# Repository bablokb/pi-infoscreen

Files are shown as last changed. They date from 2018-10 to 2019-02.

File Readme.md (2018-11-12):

Pi-Infoscreen
=============

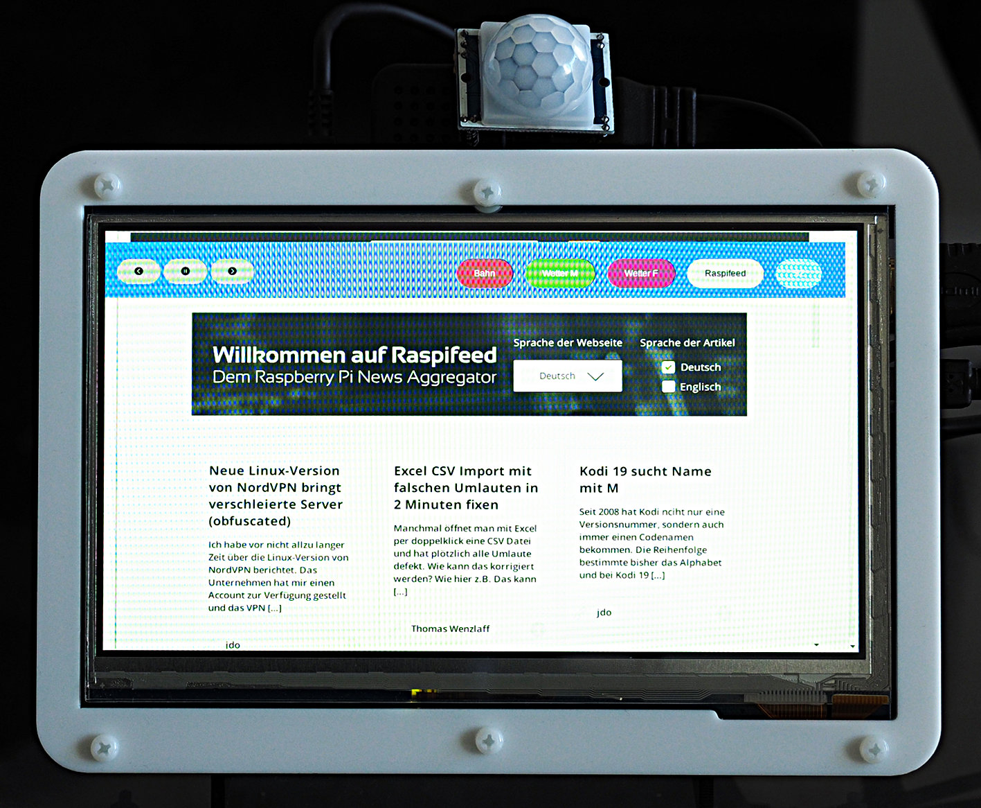
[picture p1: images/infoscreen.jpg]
The infoscreen in action


Overview
--------

This project implements a small infoscreen using a Pi and a 7"-touchscreen.
For efficiency reasons, the screen should only run while somebody is at
home, so the system automatically boots when it detects motion and automatically
shutsdown when nothing moves anymore.

Once booted, the system cycles through a list of predefined webpages.

Hardware
--------

The hardware consists of

  - a microcontroller (PIC12F675, but almost any microcontroller will do)
  - an IR motion sensor (HC-SR501, cheap and widely available)
  - a Pi3
  - a Waveshare 7"-touchscreen
  - a circuit with a P-channel mosfet

For details about the PIC and the circuit, browse the
[hardware-directory](hardware/ "hardware-directory").

Note that it is possible to run the infoscreen without the added luxury
of a PIC and/or an IR motion sensor. In case you don't have a PIC you
have to manually start the system (or let it run all the time). Since
using the sensor does not require soldering, you could use the sensor
together with the Pi to at least automatically shutdown your system.

States and Events
-----------------

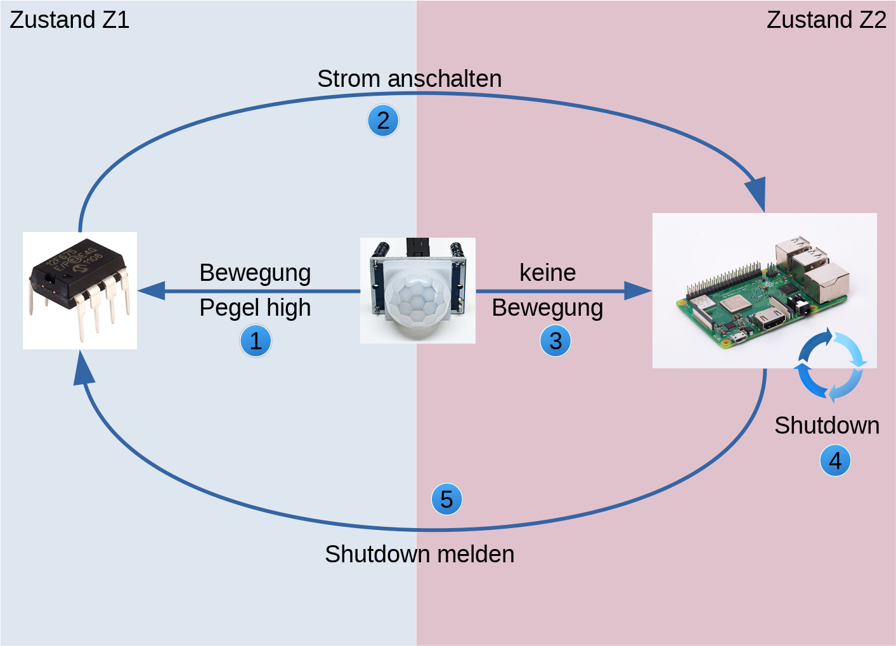
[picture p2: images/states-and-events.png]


The system starts in state "Z1": the Pi is shutdown and the PIC controls
the motion sensor (PIR). Motion will trigger a high-level on the out-pin
of the PIR, which is attached to the PIC. Now the PIC will set the gate of
the mosfet to low, thus turning on current for the Pi.

Now we are in state "Z2": the Pi is up and running and in charge of any
interrupts from the PIR. In this state the PIC is sleeping. Everytime the
Pi detects motion he will postpone his shutdown for a given time (e.g.
15 minutes). If there is no motion for 15 minutes, the Pi will shutdown
and pull Pin4 high. This is the signal for the PIC that we are back to
state "Z1" and to take over again.

Hardware Setup
--------------

The [circuit](hardware/pir_ctrl-circuit.gif "circuit") shows the wiring of
the project. The PIR-out is connected to the GP2 of the PIC as well as
GPIO17 of the Pi. In addition, GPIO4 of the Pi is connected to GP4 of the
PIC - the Pi uses this connection to signal shutdown to the PIC.

Note that this version

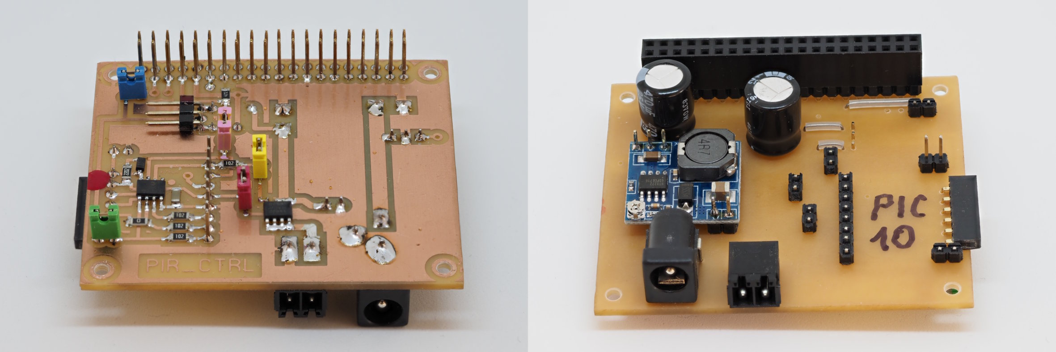
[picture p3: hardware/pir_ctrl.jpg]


also uses a step-down converter from 12V to 5V to supply a stable voltage
to the system.

Installation and Configuration
------------------------------

You should start out with a fresh install of Raspbian-Pixel desktop (tested
with Stretch, other versions might or might not work). Then run

    git clone https://github.com/bablokb/pi-infoscreen.git
    cd pi-infoscreen
    sudo tools/install
    cd ..
    git clone https://github.com/bablokb/gpio-poll-service.git
    cd gpio-poll-service
    sudo tools/install

The second install command will ask you to edit `/etc/gpio-poll.conf`, but
this is not necessary since the first install provides a suitable configuration.

*Note that the installation of the pi-infoscren project will alter your
`/boot/config.txt`. It configures HDMI for the 7"-touchscreen from Waveshare.
If you don't us this display then you must edit the file before rebooting
your system!*

The installation also modifies the autostart-behavior of the system. During
boot, it will automatically load chromium in kiosk-mode and show a local
web-page in app-mode which in turns cycles through a list of configured web-pages.

You can modify the autostart-behavior in
`/home/pi/.config/lxsession/LXDE-pi/autostart` and the list of web-pages in
`/usr/local/lib/iscreen/web/js/config.js`.

To make better use of the screen-space it is advisable to install a
so called "user-agent-switcher" within chromium from the chrome-webstore. Using
the switcher chromium can prentend to be running on a small device
(e.g. an iPhone6) and some (but not all) webpages will deliver pages
more suitable for small screens.

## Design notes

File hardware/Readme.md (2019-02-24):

Contents
========

This directory contains a number of gifs and jpegs with the circuit
and the layout of the hardware (including a gerber-file). It also
contains the assembler code used for the PIC12F675.

Assembling and Flashing
=======================

We use `gpasm` as the assembler and `pk2cmd` as flashing tools for the
PIC12F675. Both are available for the Raspberry Pi. For the latter you
also need the flashing tool /PICkit2/, which you can buy for a few
bucks on eBay.

Assembling
----------

In `pircontrol4.asm` you have to change the value of `OSCCAL`
(specific to the chip you use). Afterwards run, the assembler

    $ gpasm -a inhx8m pircontrol4.asm
    pircontrol4.asm:45:Warning [231] found lower case match for include filename

This will (re) create the file `pircontrol4.hex`.

Flashing
--------

Attach your PIC12F675 to your PICkit2 and run

    $ sudo pk2cmd -P PIC12F675 -X -M -F pircontrol4.hex
    PICkit 2 Program Report
    19-10-2018, 17:19:23
    Device Type: PIC12F675

    Program Succeeded.

    Operation Succeeded

That should be it.

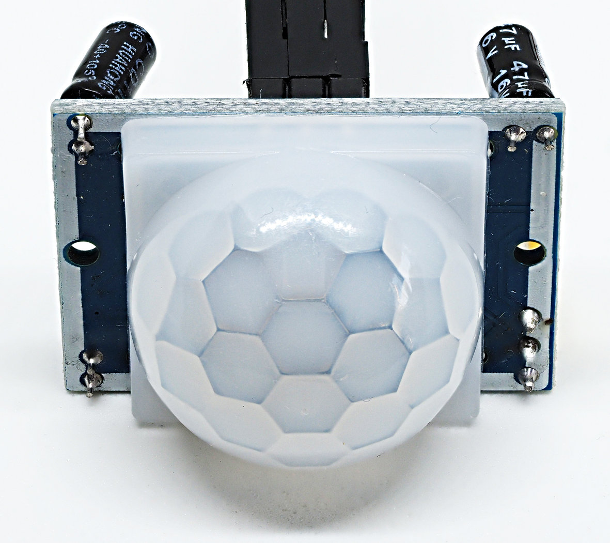
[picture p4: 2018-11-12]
hardware/HC-SR501.jpg

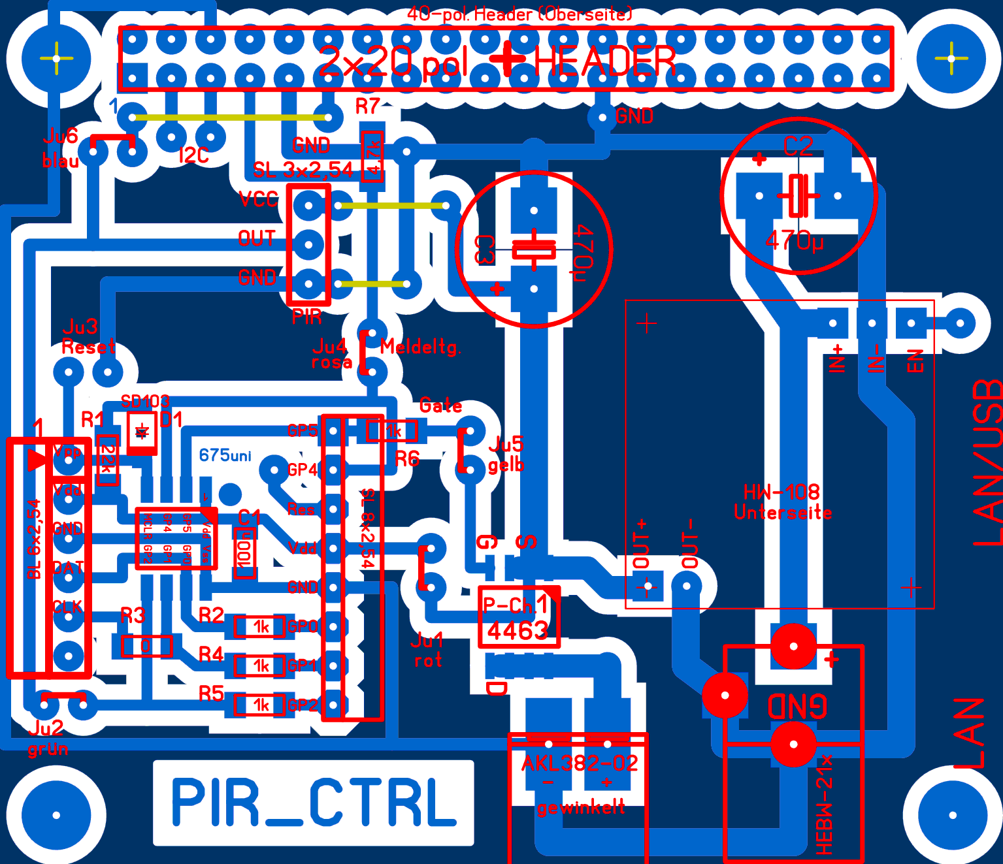
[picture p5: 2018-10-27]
hardware/pir_ctrl-layout.gif

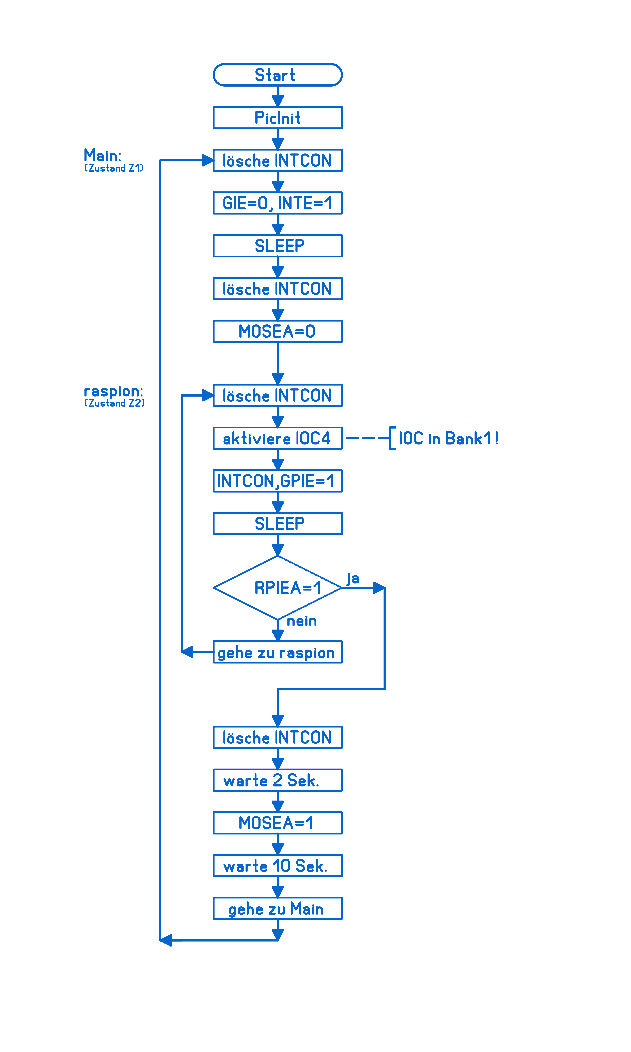
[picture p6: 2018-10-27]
hardware/pircontrol4-program-logic.gif

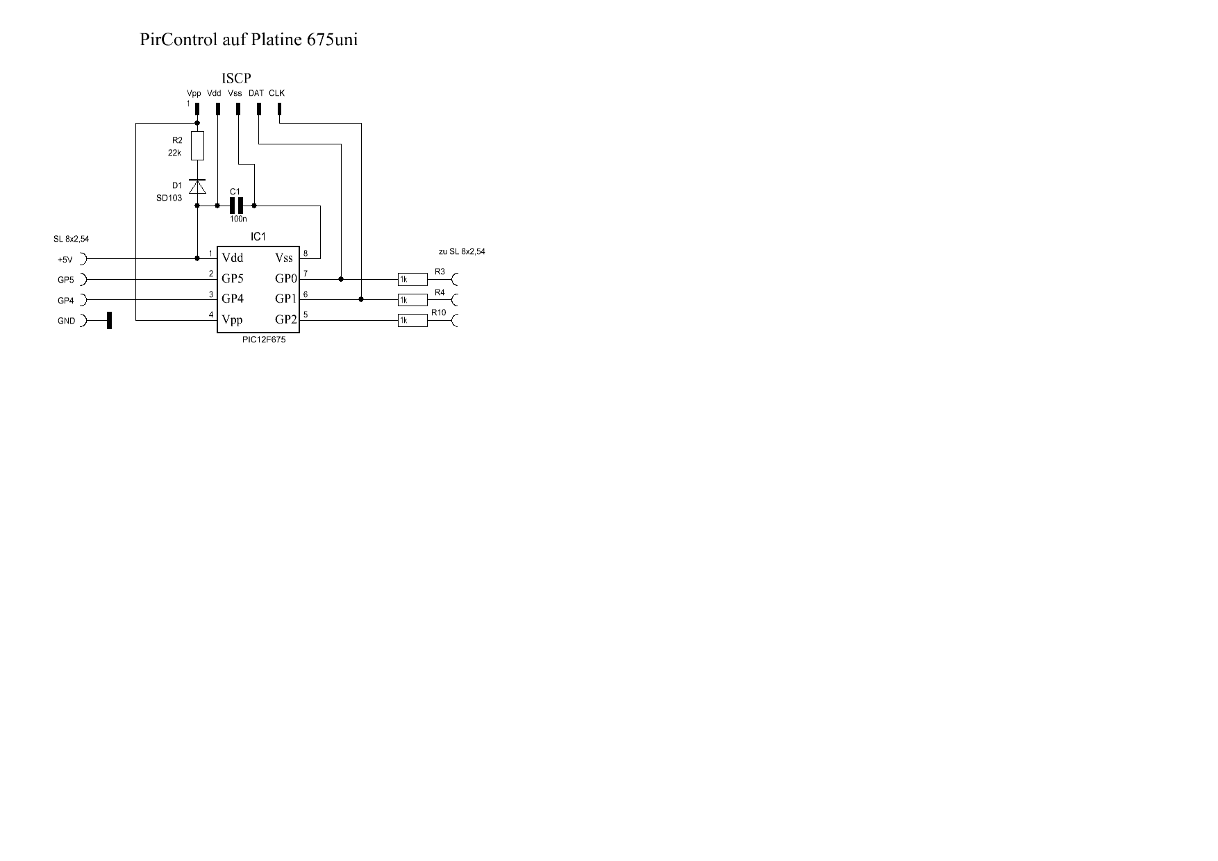
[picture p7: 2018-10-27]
hardware/675-circuit.gif

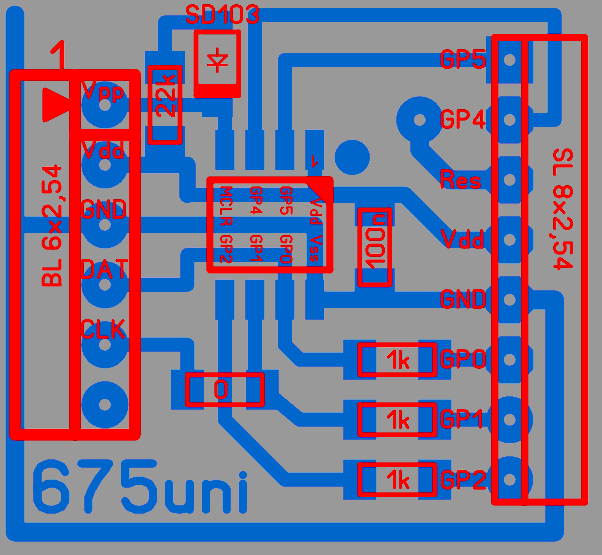
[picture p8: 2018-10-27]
hardware/675uni-layout.gif

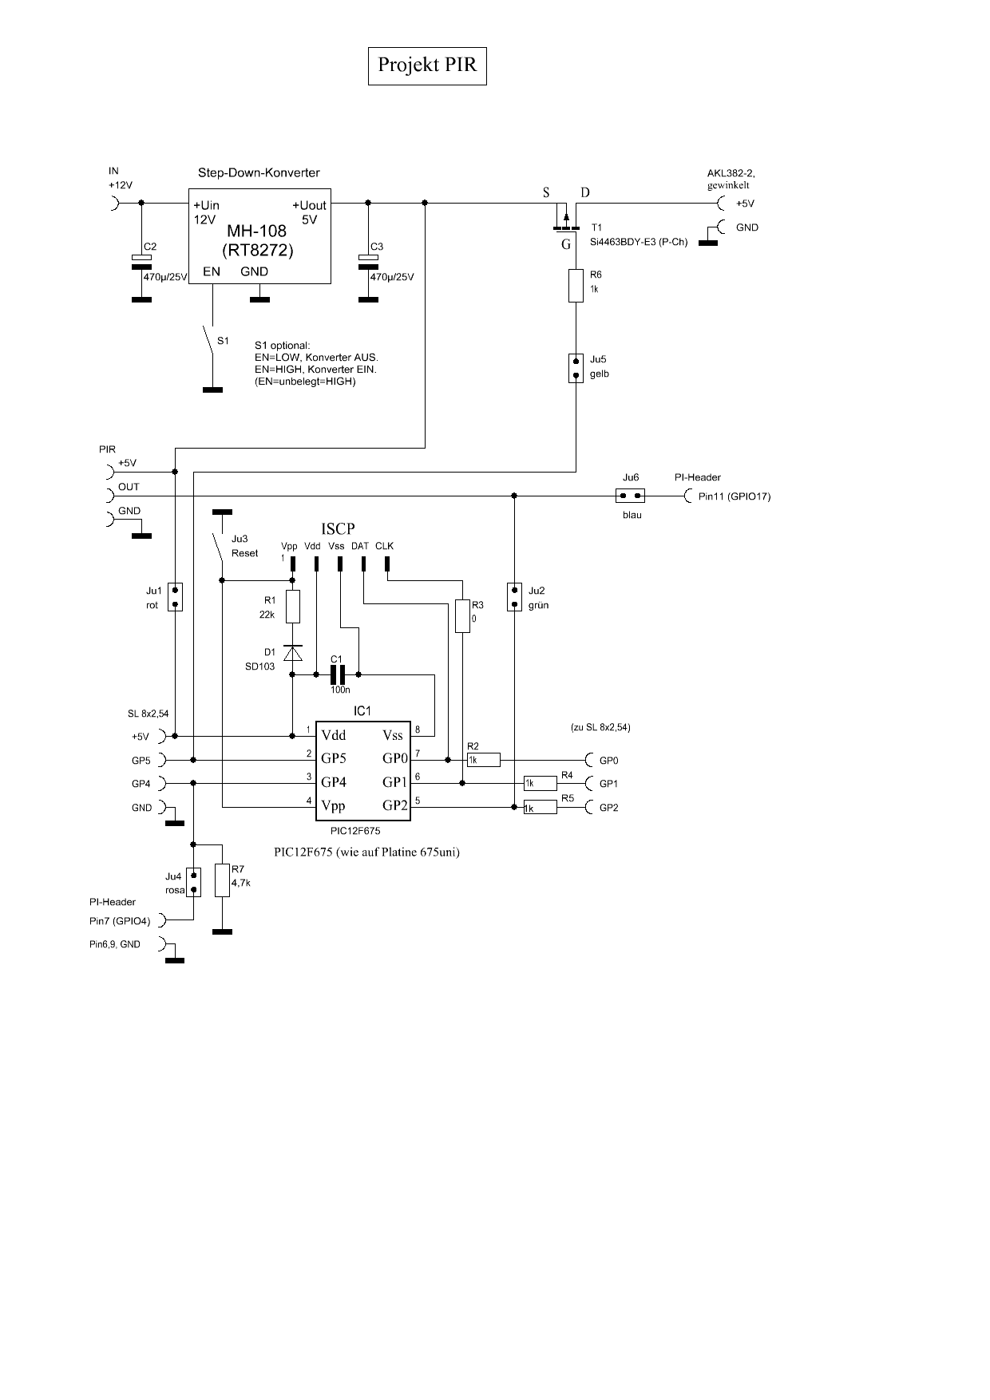
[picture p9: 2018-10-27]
hardware/pir_ctrl-circuit.gif

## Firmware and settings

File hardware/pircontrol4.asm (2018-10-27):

; pircontrol4.asm			Steinau, 12.10.2018
; ###########################################################
; IR-Bewegungsmelder-Ueberwachung mit PIC im Sleepmodus und
; einschalten eines Raspi (+5V) ueber GP5 per P-Ch-Mosfet.
; 1. Ausbau-Stufe: Test Sleep, mit LED an GP5 / Ergebnis:
; Wenn man mit High an GP2 tippt, leuchtet LED ca. 2 Sek.
; Ergebnis: 				       ok. 07.08.18
; 2. Ausbaustufe: Test PIR mit Pin OUT an GP2 / Ergebnis:
; Der PIR hat eine minimale EIN-Zeit von ca. 4-5 Sek., bevor
; diese nicht abgelaufen ist, läßt sich eine weitere Detektion
; nicht erreichen. Ergebnis:                   ok. 30.08.18
; 3. Ausbaustufe: Test der Interupts anhand der LED, rot
; Ergebnis: ok
; 4.Ausbaustufe: Endzustand komplett, mit Mosfet Si4463BDY
; Ergebnis:
; 
; ###########################################################
; Pinbelegung:
;
; GPI0	0 - GP0 Ausgang, nur ICSPDAT
;	1 - GP1 Ausgang, nur ICSPCLK
;	2 - GP2 Eingang, INT, steigende Flanke von PIR-OUT
;	3 - Vpp/MCLR
;	4 - GP4 Eingang, Meldeltg. v. Pi (Header Pin11/GPIO17)
;	5 - GP5 Ausgang, Gate T1 Mosfet Si4463
;
;	(Mosfet=Aus bei Gate=High)
;
; Prozessor-Takt 4 MHz, intern
; verwendete Platine: (Kalibrierwert OSCCAL!)
;
; Autor: Dipl.-Ing. Lothar Hiller
; ###########################################################
; Prozessor PIC12F675 (Fabrikzustand, Configuration: 01FF):
; PIC5:  OSCCAL: 3454, Bandgap: 1000, SMD, PIR, Bernh.
; PIC6:  OSCCAL: 3438, BandGap: 0000, SMD, PIR, Loth.
; PIC7:  OSCCAL: 3448, BandGap: 1000, DIL
; PIC8:  OSCCAL: 3430, BandGap: 1000, DIL, rosa
; PIC9:  OSCCAL: 3438, BandGap: 1000, DIL, lila
; PIC10: OSCCAL: 3450, BandGap: 0000, SMD, PIR_CTRL Bernh.
; ###########################################################
; Includedatei 12F675 einbinden:
	list       p=12f675
	#include   <P12f675.INC>
	ERRORLEVEL -302    ; SUPPRESS BANK SELECTION MESSAGES

; Configuration festlegen:
; MCLR ein, Power on Timer, kein WDT, int-Oscillator, 
; kein Brown out
	__CONFIG	_MCLRE_ON & _PWRTE_ON & _WDT_OFF & _INTRC_OSC_NOCLKOUT & _BODEN_OFF








; S2, Z59 ###################################################
; Variablen festlegen  (20h ... 5Fh):
; fuer Zeitverzoegerungen (UP'e in quarz_4MHz.asm)
miniteil	equ	0x20
miditeil	equ	0x21
maxiteil	equ	0x22
time0		equ	0x23
time1		equ	0x24
time2		equ	0x25
;
;
; ###########################################################
	org	0x00
	goto	PicInit		; PIC initialisieren
;
	org	0x04
				; fuer ISR, hier unbenutzt
;
	org	0x06
				; Initialisierung
PicInit
	; IO-Pins
	bcf	STATUS,RP0	; Bank0
	clrf	GPIO		; Init GPIOs
	movlw	0x07
	movwf	CMCON		; Comparator aus
	;
	; Ein/Ausgaenge und analog/digital festlegen (Bank1)
	bsf	STATUS,RP0	; Bank1
	clrf	ANSEL		; alles digital
	movlw	b'00010100'	; Eing.=1 oder Ausg.=0 festlegen:
	movwf	TRISIO		; Ausgang: GP0,1,5 Eingang: GP2,4
	;
	; OPTION_REG einstellen (Bank1)
	movlw	0xff
	movwf	OPTION_REG	; alle Bits auf high:
				; INTEDG=1 Int. bei steig. 
				; Flanke an GP2
				; PSA=1, fuer WDT unbenutzt
	;
	; internen Taktgenerator kalibrieren (Bank1)
	call	0x3FF
	movwf	OSCCAL		; 4-MHz-Kalibrierung
	bcf	STATUS,RP0	; Bank0
	;
	; Definitionen von Portpins:
;#define	PIROUT	GPIO,GP2	; pir-out an Eingang GP2
#define	RPIEA	GPIO,GP4	; Meldeleitung vom Raspi
#define	MOSEA	GPIO,GP5	; GP5 steuert gate p-Ch-Mosfet:
				; LOW=EIN, HIGH=AUS
	; GP5=1 ausgeben, damit T1 AUS ist !
	bsf	GPIO,GP5	; GP5=1, T1 AUS

	; PIR-Initialisierung abwarten:
	movlw	D'240'		; w = 240 (Dez)
	call	maxitime	; 240x250ms = 1 Min. warten
	movlw	D'240'
	call	maxitime	; noch eine Minute warten
;
; S3, Z118 ##################################################
Main
	; Zustand Z1 (PIC, GP2 ueberwacht PIR auf steig. Flanke)
	; Interruptbehandlung fuer Sleep:
	clrf	INTCON		; alle Int+Flags geloescht
	bsf	INTCON,INTE	; GP2/INT erlaubt, GIE=0 !
	SLEEP			; Sleep-Zustand aktivieren
	NOP
	clrf	INTCON		; alle INT sperren, INT-Flag=0
	;
	; PIR hat Bewegung detektiert, steigende Flanke an GP2
	; ### 4,7k von GP5 an GND:
	; Wenn GP2 kurz auf High geht (steigende Flanke), oder
	; pir-out=1, dann muss LED leuchten !
;	bsf	GPIO,GP5	; LED rot ein
	bcf	MOSEA		; MOSEA=0, Raspi ein
	; ab hier schaltet der Mosfet den Pi ein (GP5=LOW)
raspion
        ; Zustand Z2 (PIC, GP4 ueberwacht Pi auf steig. Flanke)
	clrf	INTCON		; alle Int+Flags geloescht
	bsf	STATUS,RP0	; Bank1
	bsf	IOC,IOC4	; IOC an GP4 vorbereiten
	bcf	STATUS,RP0	; Bank0
	bsf	INTCON,GPIE	; IOC erlauben
	SLEEP			; warten auf I-O-C
	NOP
	btfss	GPIO,GP4	; ist GP4=1, ueberspr. nae. Bef.
	goto	raspion		; GP4=0
	;
	; GP4=1, Pi ist heruntergefahren, kleine Warteschleife
        clrf	INTCON
        movlw   D'8'            ; w=8
        call    maxitime        ; 8x250ms = 2 Sek. warten
	;
	;Der Pi ist down, +5V abschalten
;	bcf	GPIO,GP5	; LED rot aus
	bsf	MOSEA		; MOSEA=1, Raspi aus
	; ab hier schaltet der Mosfet den Pi ab (GP5=HIGH)
	movlw	D'40'		; w = 40 (Dez)
	call	maxitime	; 40x250ms = 10 Sek. warten
	goto	Main
;
; ###########################################################
; ###########################################################
; INCLUDE von Hilfsprogrammen:
	#include <quarz_4MHz.asm>	; Zeitverzoeg.-UP'e
;
; ###########################################################
; Unterprogramme:
; ###########################################################
;
; ###########################################################
; Kalibrierwert des PIC12F675 auf Adresse 3FFH ablegen
; ###########################################################
	org	0x03FF
	retlw	0x50		; Wert v. PIC10,PIR_CTRL


; ###########################################################
	end
; Ende Datei pircontrol4.asm

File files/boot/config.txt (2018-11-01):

# For more options and information see
# http://www.raspberrypi.org/documentation/configuration/config-txt.md
# Some settings may impact device functionality. See link above for details

# uncomment if you get no picture on HDMI for a default "safe" mode
#hdmi_safe=1

# uncomment this if your display has a black border of unused pixels visible
# and your display can output without overscan
#disable_overscan=1

# uncomment the following to adjust overscan. Use positive numbers if console
# goes off screen, and negative if there is too much border
#overscan_left=16
#overscan_right=16
#overscan_top=16
#overscan_bottom=16

# uncomment to force a console size. By default it will be display's size minus
# overscan.
#framebuffer_width=1280
#framebuffer_height=720

# uncomment if hdmi display is not detected and composite is being output
#hdmi_force_hotplug=1

# uncomment to force a specific HDMI mode (this will force VGA)
#hdmi_group=1
#hdmi_mode=1

# uncomment to force a HDMI mode rather than DVI. This can make audio work in
# DMT (computer monitor) modes
#hdmi_drive=2

# uncomment to increase signal to HDMI, if you have interference, blanking, or
# no display
#config_hdmi_boost=4

# uncomment for composite PAL
#sdtv_mode=2

#uncomment to overclock the arm. 700 MHz is the default.
#arm_freq=800

# Uncomment some or all of these to enable the optional hardware interfaces
#dtparam=i2c_arm=on
#dtparam=i2s=on
#dtparam=spi=on

# Uncomment this to enable the lirc-rpi module
#dtoverlay=lirc-rpi

# Additional overlays and parameters are documented /boot/overlays/README

# Enable audio (loads snd_bcm2835)
dtparam=audio=on
gpu_mem=128

# Enable poweroff signal
dtoverlay=gpio-poweroff,gpiopin=4

# Changes for Waveshare display
max_usb_current=1
hdmi_group=2
hdmi_mode=87
hdmi_cvt 1024 600 60 6 0 0 0
hdmi_drive=1
